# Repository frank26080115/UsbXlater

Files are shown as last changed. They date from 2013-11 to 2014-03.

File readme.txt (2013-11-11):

USBXLATER - Frank Zhao

Nov 11 2013:
	USB virtual COM port functionality is working, if a PS3 is not detected, then the VCP mode will be entered, and you should be able to use it to analyze some USB stuff

	passthrough mode can start but is not sending to the FS interface yet, I need to figure out why it's not working

	major improvements to debug, and HC allocation
	fixed many hardfaults
	added COM port commands

Nov 8 2013:
	please see
	http://eleccelerator.com/usbxlater-preview/
	right now this is just a rough firmware enough to play BF4

	there is some work-in-progress code that extends the functionality to include
	VCP and traffic analysis capabilities, these are untested

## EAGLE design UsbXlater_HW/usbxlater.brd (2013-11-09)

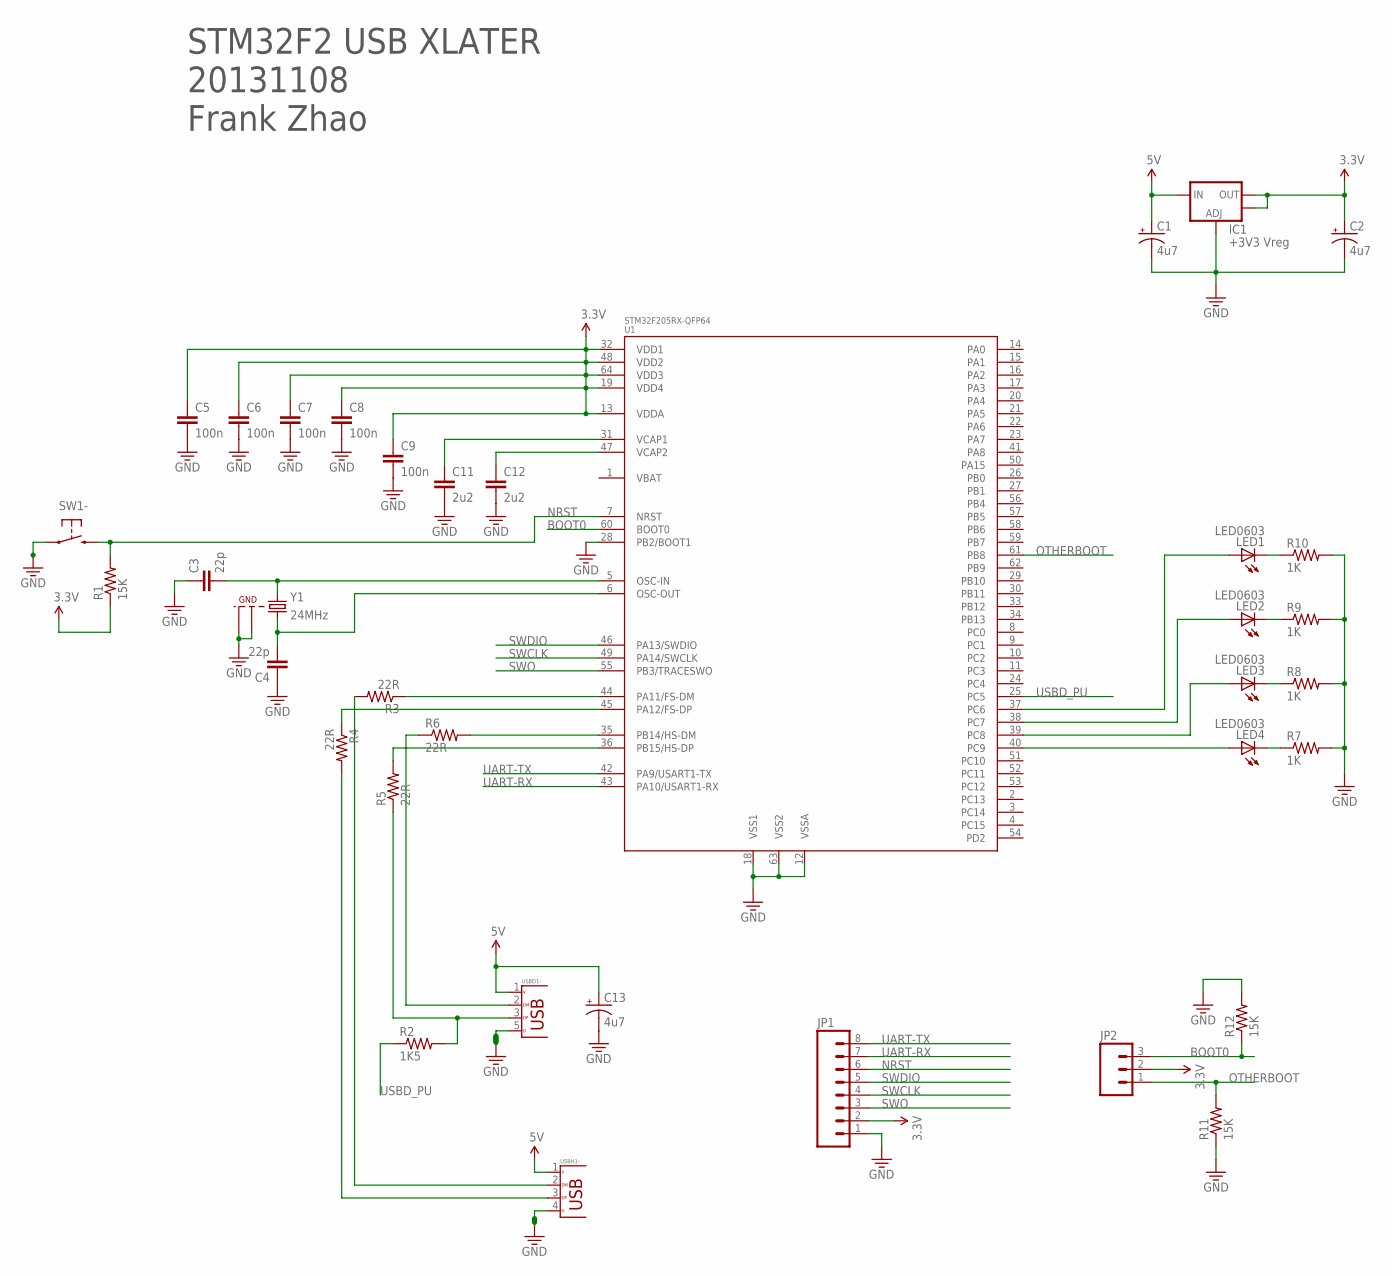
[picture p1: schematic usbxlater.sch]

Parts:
C1, C2, C13: 4u7; EIA3216
C3, C4: 22p; 0603-CAP-NOLEAK
C5, C6, C7, C8, C9: 100n; 0603-CAP-NOLEAK
C11, C12: 2u2; 0603-CAP-NOLEAK
IC1: +3V3 Vreg; SOT223
JP1: M081X08; 1X08
JP2: M03PTH; 1X03
LED1, LED2, LED3, LED4: LED0603; LED-0603
R1: 15K; 0603-RES
R2: 1K5; 0603-RES
R3, R4, R5, R6: 22R; 0603-RES
R7, R9: 1K; 0603-RES-NOLEAK
R8, R10: 1K; 0603-RES
R11, R12: 15K; 0603-RES-NOLEAK
SW1: SWITCH-B3U-1100-BOSS; SWITCH-TACT-B3U-1100P-B
U1: STM32F205RX-QFP64; TQFP64
USBD1: USB-6S-MICRO_B; USB_MICRO_B
USBH1: USB-A-RV
Y1: 24MHz; CRYSTAL-SMD-3.2X2.5

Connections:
3.3V: C2.A (+), C5.1, C6.1, C7.1, C8.1, C9.1, IC1.2 (OUT), IC1.4 (OUT), JP1.2, JP2.2, R1.1, U1.13 (VDDA), U1.19 (VDD4), U1.32 (VDD1), U1.48 (VDD2), U1.64 (VDD3)
5V: C1.A (+), C13.A (+), IC1.3 (IN), USBD1.1 (VBUS), USBH1.1 (VBUS)
BOOT0: JP2.3, R12.1, U1.60 (BOOT0)
GND: C1.C (-), C2.C (-), C3.1, C4.1, C5.2, C6.2, C7.2, C8.2, C9.2, C11.2, C12.2, C13.C (-), IC1.1 (ADJ), JP1.1, R7.2, R8.2, R9.2, R10.2, R11.1, R12.2, SW1.1, SW1.BOSS, U1.12 (VSSA), U1.18 (VSS1), U1.28 (PB2/BOOT1), U1.63 (VSS2), USBD1.5 (GND), USBD1.P$1, USBD1.P$2, USBD1.P$3, USBD1.P$4, USBD1.S1, USBD1.S2, USBH1.4 (GND), USBH1.S1, USBH1.S2, USBH1.S3, USBH1.S4, Y1.2 (GND1), Y1.4 (GND2)
unnamed: C3.2, U1.5 (OSC-IN), Y1.1
unnamed: LED1.C, R10.1
unnamed: R4.2, USBH1.3 (D+)
unnamed: R3.2, USBH1.2 (D-)
unnamed: LED2.C, R9.1
unnamed: C4.2, U1.6 (OSC-OUT), Y1.3 (2)
unnamed: C12.1, U1.47 (VCAP2)
unnamed: LED3.C, R8.1
unnamed: C11.1, U1.31 (VCAP1)
unnamed: LED4.C, R7.1
unnamed: LED4.A, U1.40 (PC9)
unnamed: R4.1, U1.45 (PA12/FS-DP)
unnamed: R3.1, U1.44 (PA11/FS-DM)
unnamed: LED3.A, U1.39 (PC8)
unnamed: LED2.A, U1.38 (PC7)
unnamed: LED1.A, U1.37 (PC6)
unnamed: R6.2, U1.35 (PB14/HS-DM)
unnamed: R5.2, U1.36 (PB15/HS-DP)
unnamed: R6.1, USBD1.2 (D-)
unnamed: R2.2, R5.1, USBD1.3 (D+)
NRST: JP1.6, R1.2, SW1.2, U1.7 (NRST)
OTHERBOOT: JP2.1, R11.2, U1.61 (PB8)
SWCLK: JP1.4, U1.49 (PA14/SWCLK)
SWDIO: JP1.5, U1.46 (PA13/SWDIO)
SWO: JP1.3, U1.55 (PB3/TRACESWO)
UART-RX: JP1.7, U1.43 (PA10/USART1-RX)
UART-TX: JP1.8, U1.42 (PA9/USART1-TX)
USBD_PU: R2.1, U1.25 (PC5)

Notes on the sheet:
STM32F2 USB XLATER 20131108 Frank Zhao

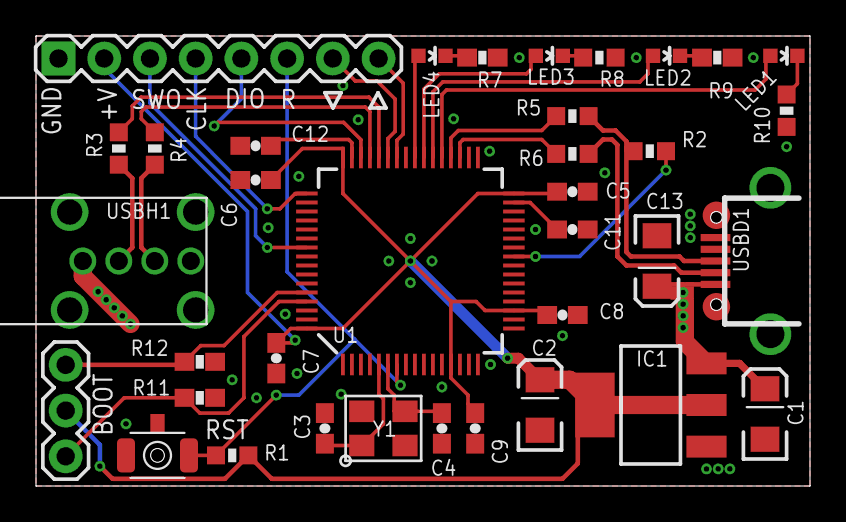
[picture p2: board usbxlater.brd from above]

Board: 2 copper layers, 43.0 x 25.0 mm, 36 parts (0 on the bottom side), 32 nets.

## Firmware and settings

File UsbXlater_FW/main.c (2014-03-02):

#include "cereal.h"
#include "led.h"
#include "vcp.h"
#include "utilities.h"
#include "crc.h"
#include "flashfile.h"
#include "ds4_emu.h"
#include "btstack/btproxy.h"
#include "btstack/hci_cereal.h"
#include <kbm2c/kbm2ctrl.h>
#include <stdlib.h>
#include <string.h>
#include <cmsis/swo.h>
#include <cmsis/core_cmFunc.h>
#include <cmsis/core_cmx.h>
#include <stm32fx/system_stm32fxxx.h>
#include <stm32fx/stm32fxxx.h>
#include <stm32fx/misc.h>
#include <stm32fx/stm32fxxx_it.h>
#include <stm32fx/peripherals.h>
#include <usbotg_lib/usb_core.h>
#include <usbotg_lib/usb_bsp.h>
#include <usbh_lib/usbh_core.h>
#include <usbh_lib/usbh_hcs.h>
#include <usbd_lib/usbd_core.h>
#include <usbh_dev/usbh_dev_manager.h>
#include <usbh_dev/usbh_devio_manager.h>
#include <usbh_dev/usbh_dev_inc_all.h>
#include <usbd_dev/usbd_dev_inc_all.h>
#include "usb_passthrough.h"

USB_OTG_CORE_HANDLE			USB_OTG_Core_dev;
USB_OTG_CORE_HANDLE			USB_OTG_Core_host;
USBH_DEV					USBH_Dev;
volatile uint32_t			systick_1ms_cnt;
volatile uint32_t			delay_1ms_cnt;

uint8_t cmdHandler();
void run_passthrough();
void run_bootload();

int main(void)
{
	SysTick_Config(SystemCoreClock / 1000); // every millisecond
	RCC_APB2PeriphClockCmd(RCC_APB2Periph_SYSCFG, ENABLE);
	__enable_irq();

	led_init();

	//cereal_init(CEREAL_BAUD_RATE);
	swo_init();

	// this step determines the default output method of debug
	// and it selects the active debug level
	dbgmode = DBGMODE_SWO
				| DBGMODE_ERR
				| DBGMODE_TRACE
				| DBGMODE_INFO
				| DBGMODE_DEBUG
				;

	//cereal_printf("\r\n\r\nhello world\r\n");

	crc_init();

	swo_printf("\r\n\r\n%s\r\n", version_string());
	swo_printf("version CRC 0x%08X\r\n", version_crc());
	swo_printf("MCU-ID %08X\r\n", DBGMCU->IDCODE);
	uint32_t* uid;
	uid = (uint32_t*)(0x1FFF7A10);
	swo_printf("Unique-ID %08X%08X%08X\r\n", uid[0], uid[1], uid[2]);

	volatile int obj = 123;
	stack_at_main = (size_t)&obj;

	flashfile_init();
	//flashfile_sectorDump();

	led_1_on(); delay_ms(150); led_1_off();
	led_2_on(); delay_ms(150); led_2_off();
	led_3_on(); delay_ms(150); led_3_off();
	led_4_on(); delay_ms(150); led_4_off();

	memset(&USB_OTG_ISR_Statistics, 0, sizeof(USB_OTG_ISR_Statistics_t));

	kbm2c_init();
	ds4emu_init();
	ds4emu_loadState();

	USBD_ExPullUp_Idle();

	USB_Hub_Hardware_Init();
	USB_Hub_Hardware_Reset();

	//dbgwdg_init();

	USB_OTG_BSP_Init(0);

	USBH_DevIOManager_Init();
	USBH_Dev_AddrManager_Reset();
	USBH_InitCore(&USB_OTG_Core_host, USB_OTG_FS_CORE_ID);
	USBH_DeAllocate_AllChannel(&USB_OTG_Core_host);
	USBH_Dev.Parent = 0;
	USBH_InitDev(&USB_OTG_Core_host, &USBH_Dev, &USBH_Dev_CB_Default);

	USB_OTG_BSP_EnableInterrupt(0);

	USBH_Dev_HID_Cnt = 0;
	USBD_CDC_IsReady = 0;

	swo_printf("Free RAM: %d\r\n", freeRam());

	// TODO, this is a simplified loop without fancy functionality, remove when testing is done
	while (1)
	{
		dbgwdg_feed();

		USBH_Process(&USB_OTG_Core_host, &USBH_Dev);

		ds4emu_task();
	}

	return 0;
}

void SysTick_Handler(void)
{
	if (delay_1ms_cnt > 0) {
		delay_1ms_cnt--;
	}

	systick_1ms_cnt++;

	if ((systick_1ms_cnt % 2000) == 0)
	{
		dbg_printf(DBGMODE_DEBUG, "%d %d , ", systick_1ms_cnt, freeRam());
		dbg_printf(DBGMODE_DEBUG, "%d %d , ", proxy_stats.ds2bt_hidctrl_cnt, proxy_stats.bt2ps_hidctrl_cnt);
		dbg_printf(DBGMODE_DEBUG, "%d %d , ", proxy_stats.ds2bt_hidctrl_len, proxy_stats.bt2ps_hidctrl_len);
		dbg_printf(DBGMODE_DEBUG, "%d %d %d , ", proxy_stats.ds2bt_hidintr_cnt, proxy_stats.ds2bt_hidintr_highprior_cnt, proxy_stats.bt2ps_hidintr_cnt);
		dbg_printf(DBGMODE_DEBUG, "%d %d %d , ", proxy_stats.ds2bt_hidintr_len, proxy_stats.ds2bt_hidintr_highprior_len, proxy_stats.bt2ps_hidintr_len);
		dbg_printf(DBGMODE_DEBUG, "%d %d , ", proxy_stats.ps2bt_hidctrl_cnt, proxy_stats.bt2ds_hidctrl_cnt);
		dbg_printf(DBGMODE_DEBUG, "%d %d , ", proxy_stats.ps2bt_hidctrl_len, proxy_stats.bt2ds_hidctrl_len);
		dbg_printf(DBGMODE_DEBUG, "%d %d , ", proxy_stats.ps2bt_hidintr_cnt, proxy_stats.bt2ds_hidintr_cnt);
		dbg_printf(DBGMODE_DEBUG, "%d %d , ", proxy_stats.ps2bt_hidintr_len, proxy_stats.bt2ds_hidintr_len);
		dbg_printf(DBGMODE_DEBUG, "\r\n");
	}

	//if ((systick_1ms_cnt % 2000) == 0 && dbg_obj != 0) dbg_printf(DBGMODE_DEBUG, "sth %d %d\r\n", systick_1ms_cnt, ((USBH_DevIO_t*)dbg_obj)->state);
	//if (hal_tick_handler != 0) hal_tick_handler();
}

void run_passthrough()
{
	dbg_printf(DBGMODE_TRACE, "\r\n Entering Pass-Through Mode\r\n");

	// force a disconnection
	HCD_ResetPort(&USB_OTG_Core_host);
	USBH_DeInit(&USB_OTG_Core_host, &USBH_Dev);
	USBH_DeAllocate_AllChannel(&USB_OTG_Core_host);
	DCD_DevDisconnect(&USB_OTG_Core_dev);
	USBD_DeInit(&USB_OTG_Core_dev);

	// force full reset of both cores
	USB_OTG_CoreReset(&USB_OTG_Core_host);
	USB_OTG_CoreReset(&USB_OTG_Core_dev);

	// small disconnection delay
	delay_1ms_cnt = 200;
	while (delay_1ms_cnt > 0) dbgwdg_feed();

	USBPT_Init(&USBH_Dev);

	while (1) {
		dbgwdg_feed();
		USBPT_Work();
	}
}

void run_bootload()
{
	dbg_printf(DBGMODE_TRACE, "\r\n Entering Bootloader Mode\r\n");

	// small delay for trace message
	delay_1ms_cnt = 200;
	while (delay_1ms_cnt > 0) dbgwdg_feed();

	dbgwdg_stop();

	jump_to_bootloader();
}

// return 0 to signal "nothing to handle", return a code if the caller should handle something
uint8_t cmdHandler()
{
	static char cmdBuff[32];
	static int cmdBuffIdx = 0;

	int16_t c = vcp_rx();
	if (c < 0) {
		c = cereal_rx();
	}

	if (c >= 0)
	{
		if (c == '\r' || c == '\n' || c == '\0')
		{
			if (strcmp(cmdBuff, "passthrough") == 0)
			{
				return 1;
			}
			else if (strcmp(cmdBuff, "bootload") == 0)
			{
				return 2;
			}
			else if (strcmp(cmdBuff, "reset") == 0)
			{
				return 3;
			}
			else
			{
				dbgwdg_feed();
				vcp_printf("\r\nunknown command: \"%s\"\r\n", cmdBuff);
				cereal_printf("\r\nunknown command: \"%s\"\r\n", cmdBuff);
			}

			cmdBuffIdx = 0;
			return 0;
		}
		else
		{
			if (cmdBuffIdx < 32)
			{
				cmdBuff[cmdBuffIdx] = c;
				cmdBuffIdx++;
				cmdBuff[cmdBuffIdx] = 0;
			}
		}
	}

	return 0;
}

// an external pull-up resistor is implemented because soft-disconnect doesn't work too well

void USBD_ExPullUp_Idle()
{
	RCC_AHB1PeriphClockCmd(RCC_AHB1Periph_GPIOC, ENABLE);
	GPIO_InitTypeDef gi;
	GPIO_StructInit(&gi);
	gi.GPIO_Mode = GPIO_Mode_IN;
	gi.GPIO_Pin = GPIO_Pin_5;
	gi.GPIO_PuPd = GPIO_PuPd_NOPULL;
	GPIO_Init(GPIOC, &gi);
}

void USBD_ExPullUp_On()
{
	RCC_AHB1PeriphClockCmd(RCC_AHB1Periph_GPIOC, ENABLE);
	GPIO_InitTypeDef gi;
	GPIO_StructInit(&gi);
	gi.GPIO_Mode = GPIO_Mode_OUT;
	gi.GPIO_Pin = GPIO_Pin_5;
	GPIO_Init(GPIOC, &gi);
	GPIO_SetBits(GPIOC, GPIO_Pin_5);
}

void USBD_ExPullUp_Off()
{
	RCC_AHB1PeriphClockCmd(RCC_AHB1Periph_GPIOC, ENABLE);
	GPIO_InitTypeDef gi;
	GPIO_StructInit(&gi);
	gi.GPIO_Mode = GPIO_Mode_OUT;
	gi.GPIO_Pin = GPIO_Pin_5;
	GPIO_Init(GPIOC, &gi);
	GPIO_ResetBits(GPIOC, GPIO_Pin_5);
}

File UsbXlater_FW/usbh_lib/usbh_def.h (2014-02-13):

/**
  ******************************************************************************
  * @file    usbh_def.h
  * @author  MCD Application Team
  * @version V2.1.0
  * @date    19-March-2012
  * @brief   Definitions used in the USB host library
  ******************************************************************************
  * @attention
  *
  * <h2><center>&copy; COPYRIGHT 2012 STMicroelectronics</center></h2>
  *
  * Licensed under MCD-ST Liberty SW License Agreement V2, (the "License");
  * You may not use this file except in compliance with the License.
  * You may obtain a copy of the License at:
  *
  *        http://www.st.com/software_license_agreement_liberty_v2
  *
  * Unless required by applicable law or agreed to in writing, software 
  * distributed under the License is distributed on an "AS IS" BASIS, 
  * WITHOUT WARRANTIES OR CONDITIONS OF ANY KIND, either express or implied.
  * See the License for the specific language governing permissions and
  * limitations under the License.
  *
  ******************************************************************************
  */ 

/** @addtogroup USBH_LIB
  * @{
  */

/** @addtogroup USBH_LIB_CORE
* @{
*/
  
/** @defgroup USBH_DEF
  * @brief This file is includes USB descriptors
  * @{
  */ 

#ifndef  USBH_DEF_H
#define  USBH_DEF_H

#ifndef USBH_NULL
#define USBH_NULL ((void *)0)
#endif

#ifndef FALSE
#define FALSE 0
#endif

#ifndef TRUE
#define TRUE 1
#endif


#define ValBit(VAR,POS)                               (VAR & (1 << POS))
#define SetBit(VAR,POS)                               (VAR |= (1 << POS))
#define ClrBit(VAR,POS)                               (VAR &= ((1 << POS)^255))

#define  LE16(addr)             (((u16)(*((u8 *)(addr))))\
                                + (((u16)(*(((u8 *)(addr)) + 1))) << 8))

#define  USB_LEN_DESC_HDR                               0x02
#define  USB_LEN_DEV_DESC                               0x12
#define  USB_LEN_CFG_DESC                               0x09
#define  USB_LEN_IF_DESC                                0x09
#define  USB_LEN_EP_DESC                                0x07
#define  USB_LEN_OTG_DESC                               0x03
#define  USB_LEN_SETUP_PKT                              0x08

/* bmRequestType :D7 Data Phase Transfer Direction  */
#define  USB_REQ_DIR_MASK                               0x80
#define  USB_H2D                                        0x00
#define  USB_D2H                                        0x80

/* bmRequestType D6..5 Type */
#define  USB_REQ_TYPE_STANDARD                          0x00
#define  USB_REQ_TYPE_CLASS                             0x20
#define  USB_REQ_TYPE_VENDOR                            0x40
#define  USB_REQ_TYPE_RESERVED                          0x60

/* bmRequestType D4..0 Recipient */
#define  USB_REQ_RECIPIENT_DEVICE                       0x00
#define  USB_REQ_RECIPIENT_INTERFACE                    0x01
#define  USB_REQ_RECIPIENT_ENDPOINT                     0x02
#define  USB_REQ_RECIPIENT_OTHER                        0x03

/* Table 9-4. Standard Request Codes  */
/* bRequest , Value */
#define  USB_REQ_GET_STATUS                             0x00
#define  USB_REQ_CLEAR_FEATURE                          0x01
#define  USB_REQ_SET_FEATURE                            0x03
#define  USB_REQ_SET_ADDRESS                            0x05
#define  USB_REQ_GET_DESCRIPTOR                         0x06
#define  USB_REQ_SET_DESCRIPTOR                         0x07
#define  USB_REQ_GET_CONFIGURATION                      0x08
#define  USB_REQ_SET_CONFIGURATION                      0x09
#define  USB_REQ_GET_INTERFACE                          0x0A
#define  USB_REQ_SET_INTERFACE                          0x0B
#define  USB_REQ_SYNCH_FRAME                            0x0C

/* Table 9-5. Descriptor Types of USB Specifications */
#define  USB_DESC_TYPE_DEVICE                              1
#define  USB_DESC_TYPE_CONFIGURATION                       2
#define  USB_DESC_TYPE_STRING                              3
#define  USB_DESC_TYPE_INTERFACE                           4
#define  USB_DESC_TYPE_ENDPOINT                            5
#define  USB_DESC_TYPE_DEVICE_QUALIFIER                    6
#define  USB_DESC_TYPE_OTHER_SPEED_CONFIGURATION           7
#define  USB_DESC_TYPE_INTERFACE_POWER                     8
#define  USB_DESC_TYPE_HID                                 0x21
#define  USB_DESC_TYPE_HID_REPORT                          0x22


#define USB_DEVICE_DESC_SIZE                               18
#define USB_CONFIGURATION_DESC_SIZE                        9
#define USB_HID_DESC_SIZE                                  9
#define USB_INTERFACE_DESC_SIZE                            9
#define USB_ENDPOINT_DESC_SIZE                             7
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

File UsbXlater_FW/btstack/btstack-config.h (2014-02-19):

#ifndef BTSTACK_CONFIG_H_
#define BTSTACK_CONFIG_H_

#define EMBEDDED
#define HAVE_TICK
#define HAVE_MALLOC

//#define ENABLE_LOG_INFO
#define ENABLE_LOG_ERROR
#define SDP_DES_DUMP

#define HCI_ACL_PAYLOAD_SIZE 1024

#define MAX_SPP_CONNECTIONS 0

#define MAX_NO_HCI_CONNECTIONS 4
#define MAX_NO_L2CAP_SERVICES  6
#define MAX_NO_L2CAP_CHANNELS  6
#define MAX_NO_RFCOMM_MULTIPLEXERS 0
#define MAX_NO_RFCOMM_SERVICES 0
#define MAX_NO_RFCOMM_CHANNELS 0
#define MAX_NO_DB_MEM_DEVICE_LINK_KEYS  2
#define MAX_NO_DB_MEM_DEVICE_NAMES 2
#define MAX_NO_DB_MEM_SERVICES 2

//#define FORCE_SSP

//#define HAVE_SDP_EXTRA_QUERIES

#endif

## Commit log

2013-11-09 vcp working, tried to improve parser, and more...
    new startup sequencing
    better usage of external pull-up resistor
    improved system timer
2013-11-10 fixed bugs, improved hc alloc, tried to make passthrough work, added cmd handler
    [main.c]
2013-11-19 dualshock4 emu, watchdog timer, not a clean commit
2013-11-19 DS4 SetFeature 0x14 supported, still doesn't actually respond
    [main.c]
2013-11-22 fix for set_idle stalling
2014-01-03 added stm32f4
    [STM32F4xx_Clock_Configuration_V1.1.xlsm]
2014-01-12 fix for stm32f4 clock
    [STM32F4xx_Clock_Configuration_V1.1.0.xls, STM32F4xx_Clock_Configuration_V1.1.xlsm]
2014-02-19 more usb fixes, complete BT connection from DS4
    [btproxy.c, btstack-config.h]
2014-02-24 bt connects ps4, fixed mixed pkt type in xpo
    [hci_transport_stm32usbh.c]
2014-03-02 bf4 playable
    see
    http://eleccelerator.com/keyboard-and-mouse-for-playstation-4-games-second-prototype/

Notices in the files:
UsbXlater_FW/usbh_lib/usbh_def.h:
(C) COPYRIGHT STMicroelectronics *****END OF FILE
